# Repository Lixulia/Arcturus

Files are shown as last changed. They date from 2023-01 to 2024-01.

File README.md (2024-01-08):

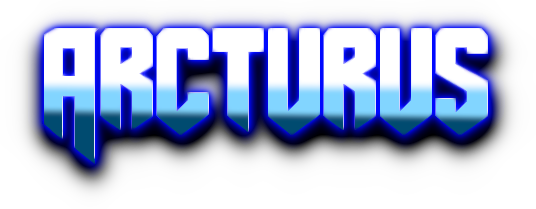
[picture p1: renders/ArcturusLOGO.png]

# *Design by Whitney/Lixulia*
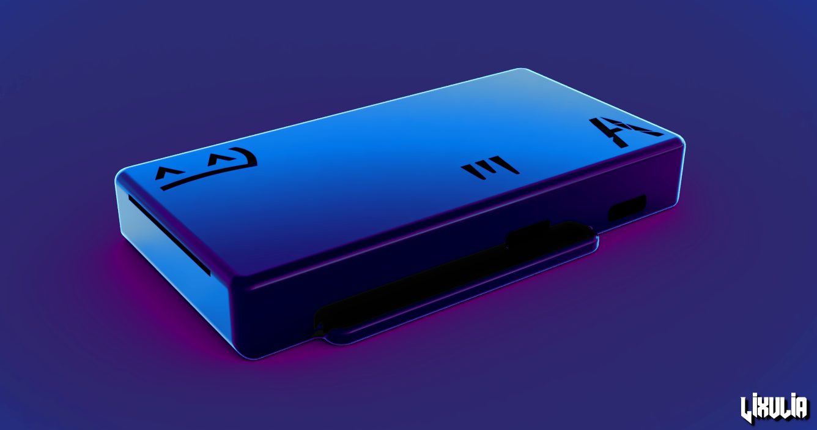
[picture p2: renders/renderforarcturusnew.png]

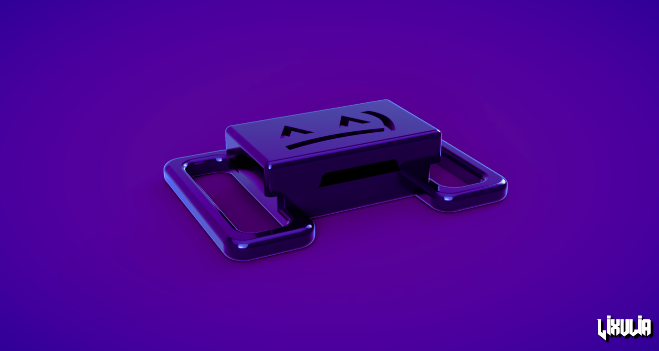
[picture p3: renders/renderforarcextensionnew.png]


# **ARCTURUS IS NOW A FULLY OPEN SOURCE PROJECT AND I WILL BE TAKING A TEMP LEAVE FROM IT!!**
*File directory for Arcturus, a SlimeVR case. (winterx renamed and completely redone)*

Hi! Here youll find the files for printing the arcturus case, and its extension case. These are the sucessors to the winterx and xtension cases.

This case is for the following compentents : 
- 804040 Battery (or smaller)
- BMI160
- Wemos D1 Mini (micro b version)
- tp4056 type C
- 26AWG wire (or smaller. Nothing bigger.)
- Aliexpress Power Switch (DPDT 2P2T)
- 2in elastic straps (Main case) or 1.5, it works too.
- 1in elastic straps (extensions)

**Recommended Print settings:**
- 20% infill
- No supports necassary
- .2mm print quality

You can download both the case and extension files in one zip in the releases.

*Recently I moved things into folders for cleanliness*

Dovetail version is now main case.

Just added alt lid versions, with body locations engraved into them.

**For lids**:
- LA or RA = Left or right arm.
- LL or RL = Left or right leg.
- LF or RF = Left or right ankle, or foot. *This is due to the shorthand A being taken by arm already.*
- HIP or CH = Hip or chest.

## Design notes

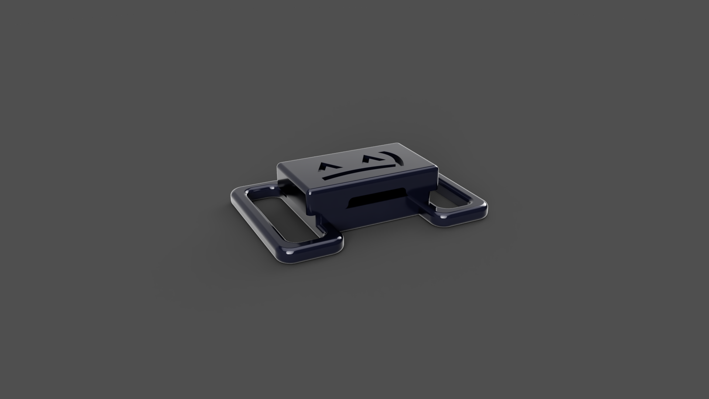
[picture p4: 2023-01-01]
renders/ArcExtensionRender.png

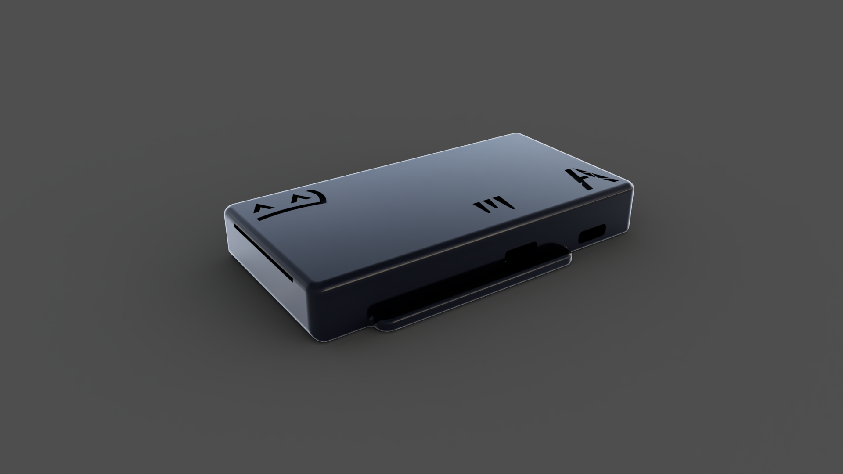
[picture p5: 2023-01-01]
renders/renderforarcturus.PNG

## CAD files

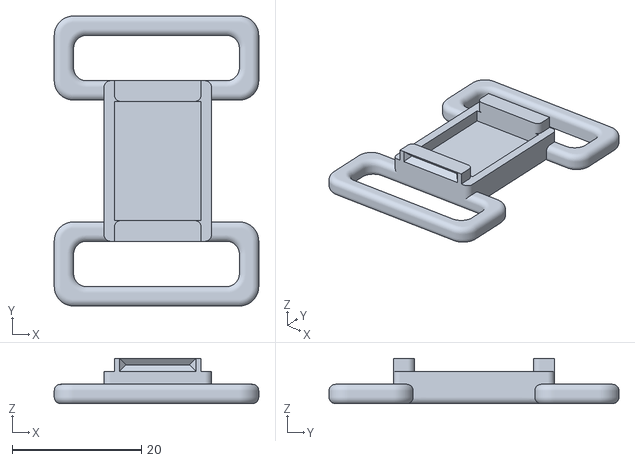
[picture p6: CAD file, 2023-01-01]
Extension Files/ArcExtension-Bottom.stl
31.6 x 44.8 x 7.00

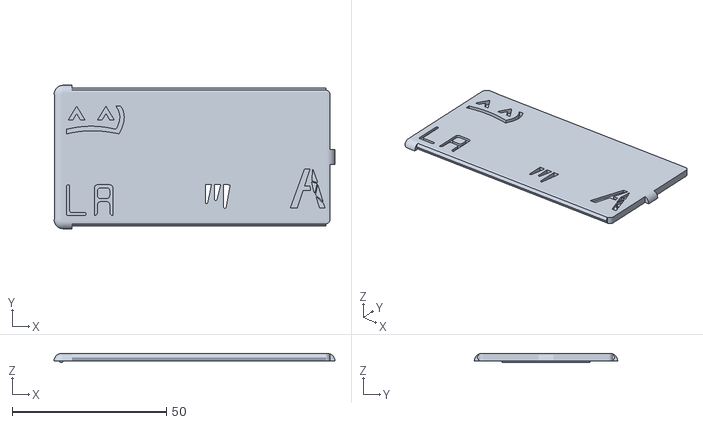
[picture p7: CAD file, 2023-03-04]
LocationMarkerLids/LeftArmLid.stl
91.2 x 46.6 x 2.98

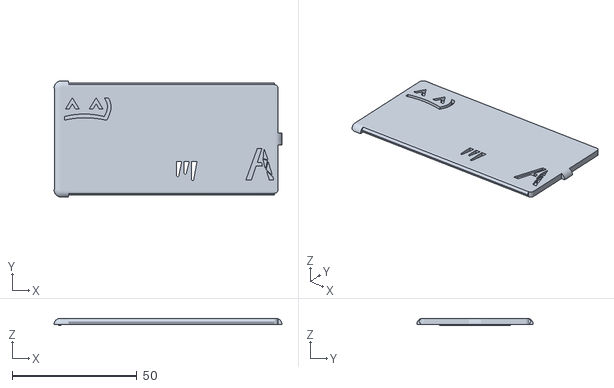
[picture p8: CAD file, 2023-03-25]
Main Case Files/ArcturusLid.stl
91.2 x 46.6 x 2.98

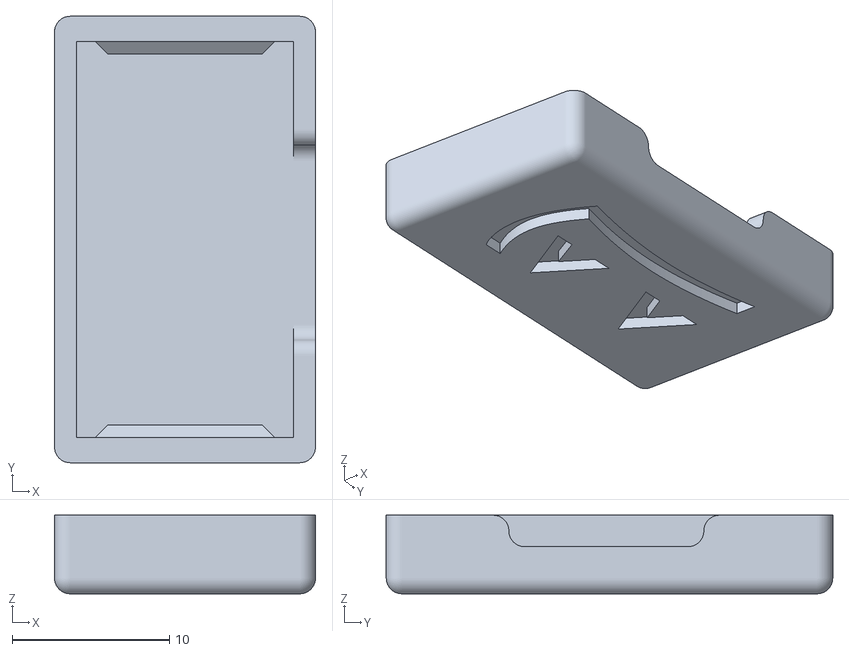
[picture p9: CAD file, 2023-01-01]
Extension Files/ArcExtension-Top.stl
16.6 x 28.4 x 5.00

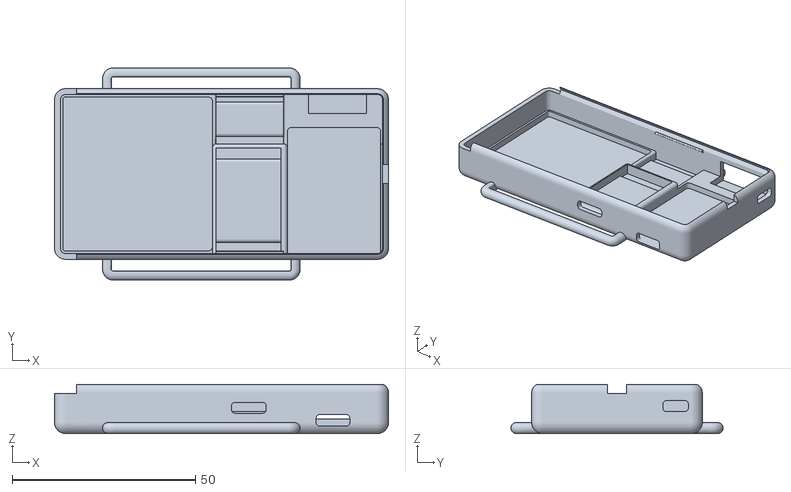
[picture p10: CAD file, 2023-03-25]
Main Case Files/ArcturusBottomNew.stl
91.2 x 58.0 x 13.4

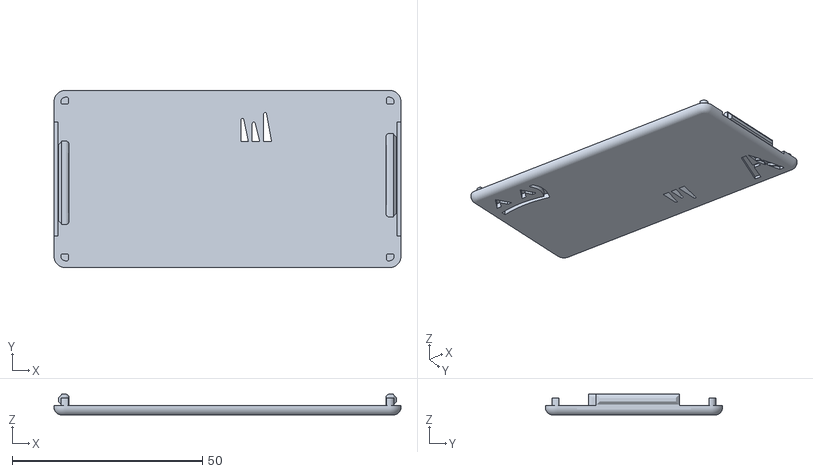
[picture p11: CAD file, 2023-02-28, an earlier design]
old versions/ArcturusOldVersTop.stl
91.2 x 46.6 x 5.50

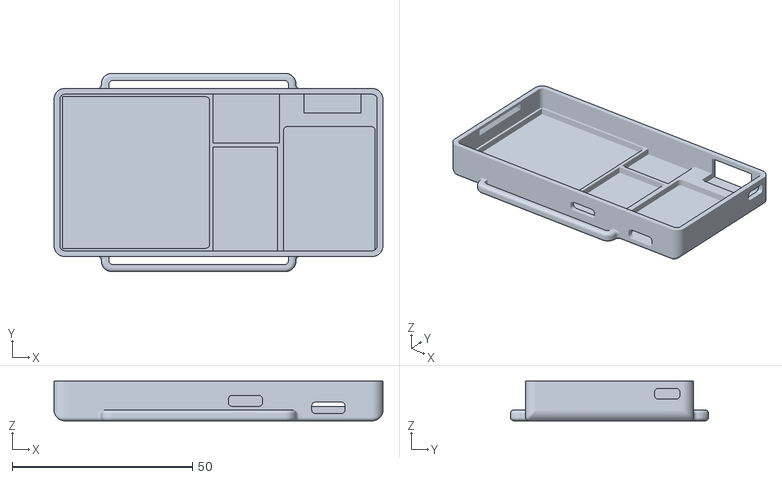
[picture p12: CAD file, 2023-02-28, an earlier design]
old versions/ArcturusOldVersBottom.stl
91.2 x 55.0 x 11.0

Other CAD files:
LocationMarkerLids/RightFootLid.stl
LocationMarkerLids/RightArmLid.stl
LocationMarkerLids/ChestLid.stl
LocationMarkerLids/LeftFootLid.stl
LocationMarkerLids/HipLid.stl
LocationMarkerLids/LeftLegLid.stl
LocationMarkerLids/RightLegLid.stl
Fusion Files/ArcturusV3 Dovetail attempt v15.f3d
old versions/ArcturusV3 v8.f3d

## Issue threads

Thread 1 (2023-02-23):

How to put together?

RRenzo, 2023-02-23:
Is there any guide on how the components should be put together in the case? I have bought all the components that are listed as compatible with the Arturus case and I have also 3d printed all the main cases and extensions that I need for my SlimeVR setup.

Lixulia, 2023-02-24:
https://photos.app.goo.gl/i6C6iSW95ACs4k7F7

Battery in the big slot, type c in the middle, d1 to the far left, and switch in the side wall hole. The bmi goes in the rectangle slot

Closed 2023-02-24.

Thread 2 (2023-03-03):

50 x 34 x 6 mm battery fit

StellaWaa, 2023-03-03:
Hi, will a 50 x 34 x 6 mm battery fit in this case?

Lixulia, 2023-03-03:
No, but I plan to upload the fusion files for easier modifications. It would need to be 10mm longer. That's kinda a lot, so I would consider my other case, solaris, unless you don't mind arcturus being longer.

Closed 2023-03-03.

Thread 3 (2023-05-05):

My adventure with this case

S-y-c-h-o, 2023-05-05:
I have done alot of work with this case, specifically modifying it to meet my individual needs. Such as:

Enlarged / moved port holes
Added hole for JST female port
Removed hole for extension wires
Reinforced case next to JST hole as case snapped on multiple occasions
Switch hole enlarged
Riser added to back of microcontroller spot
Indent added to front microcontroller spot
Raised 'walls' next to microcontroller so that the previous two edits don't make the microcontroller sit above the 'walls'
^ (These allow the microcontroller to sit flat and snap in
The lid's dovetail is not the same on both sides. ?
Lid's details were creating strange toolpaths, made them far thinner and removed through-hole
Dovetail on case too thin and broke easily (it was less than .2 mm thick on multiple layers), enlarged by 1mm on both sides
Dovetail lid modified to cooperate with previous edit
Removed lid supports on case

A number of these edits were personal preferance, but i think that some may be implemented into the case for all users. I can send a copy of the edited case if desired.
Note: I have had to compensate for my printer's relatively poor accuracy, and many of these edits may not have been needed to be made if the printer did not necessitate a part with larger tolerances.
Also note: first time posting on github and also 3d printing. i claim to be no expert. pls go easy on me.

Lixulia, 2023-05-07:
Hello! You can post your own versions and edits online, Idc. This is a public case that I made for public use. Im temporarily giving up on fixing every little thing people complain about, and who knows, maybe someday ill come back and fix it. For now, Im just gonna upload the fusion files so people can do whatever. Have fun! closing this now.

Closed 2023-05-07.

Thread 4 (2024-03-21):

One corner of case lifts when printing even with a brim

thebitmaster, 2024-03-21:
Great work on these cases! I really like your design.
I've printed two of them out of PETG with a brim, and both times the edge next to the largest hole lifted at the bottom even though there was a brim. It actually pulled away from the brim, which stayed on the build plate. I did one print without part cooling, and on with it on at 100% and the results were the same. I know Fusion 360 and will see if I can find a mod that might fix the problem. My settings were 0.2mm layer height, 20% infill, print cooling on once and off once, no support, with a build plate at 60 o C and print temp at 230 o C. I leveled the bed with a BL Touch before printing.
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

Spiksee3, 2024-05-27:
it's probably because of the rounded corners on the bottom, i'd say just edit them out.
